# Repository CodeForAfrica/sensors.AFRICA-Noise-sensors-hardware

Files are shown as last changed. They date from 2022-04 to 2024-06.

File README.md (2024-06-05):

# sensors.AFRICA Noise Sensor Kits Hardware

## Tools used

* Autodesk Eagle

* Fusion360

## sensors.AFRICA Stack

1. Firmware - https://github.com/CodeForAfrica/sensors.AFRICA-Noise-sensors-software
2. API - https://github.com/CodeForAfricaLabs/sensors.AFRICA-AQ-api
3. Map - https://github.com/CodeForAfrica/sensors.AFRICA-AQ-map-v2

## Documentation

Latest PCB Design on](https://a360.co/4bMNexy) Fusion360

*Front layer*
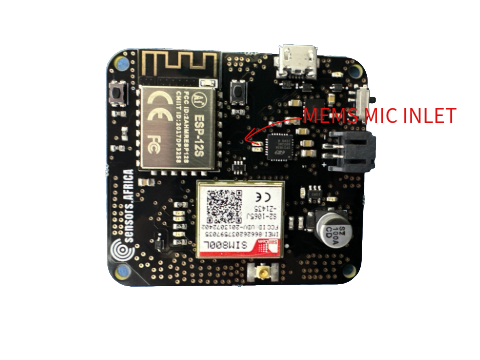
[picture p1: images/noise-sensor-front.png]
Front layer
 

*Back layer*
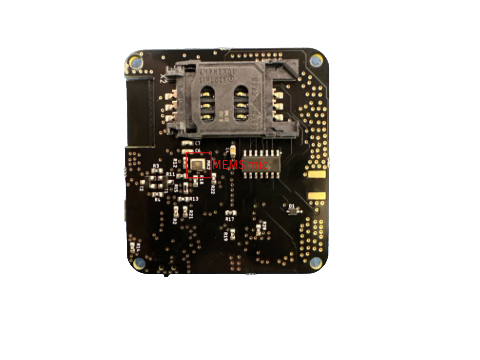
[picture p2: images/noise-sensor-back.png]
Back layer


### Pinout 
- **RX** and **TX** pins on the ESP-12 to communicate to the GSM are **0** and **2** respectively.
- The **GSM RESET** pin is **NOT** physically connected to the ESP module.

## License

GNU General Public License v3.0

sensors.AFRICA is a citizen-science focused project by Code for Africa that seeks to address data gaps by providing low cost sensors, which people can use to measure and monitor the quality of the air, water, and environment in their communities. This web app seeks to be the public portal through which most users would discover and explore the data and intiative.

Copyright (C) 2022 Code for Africa

This program is free software: you can redistribute it and/or modify
it under the terms of the GNU General Public License as published by
the Free Software Foundation, either version 3 of the License, or
(at your option) any later version.

This program is distributed in the hope that it will be useful,
but WITHOUT ANY WARRANTY; without even the implied warranty of
MERCHANTABILITY or FITNESS FOR A PARTICULAR PURPOSE. See the
GNU General Public License for more details.

You should have received a copy of the GNU General Public License
along with this program. If not, see <https://www.gnu.org/licenses/>

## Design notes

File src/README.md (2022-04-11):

# sensors.AFRICA / Noise sensors hardware

This folder contains the Eagle design files for the sensors.AFRICA Noise Sensor boards.

### Folders

* **Noise sensor** The Printed Circuit Board of the Noise Sensor kit

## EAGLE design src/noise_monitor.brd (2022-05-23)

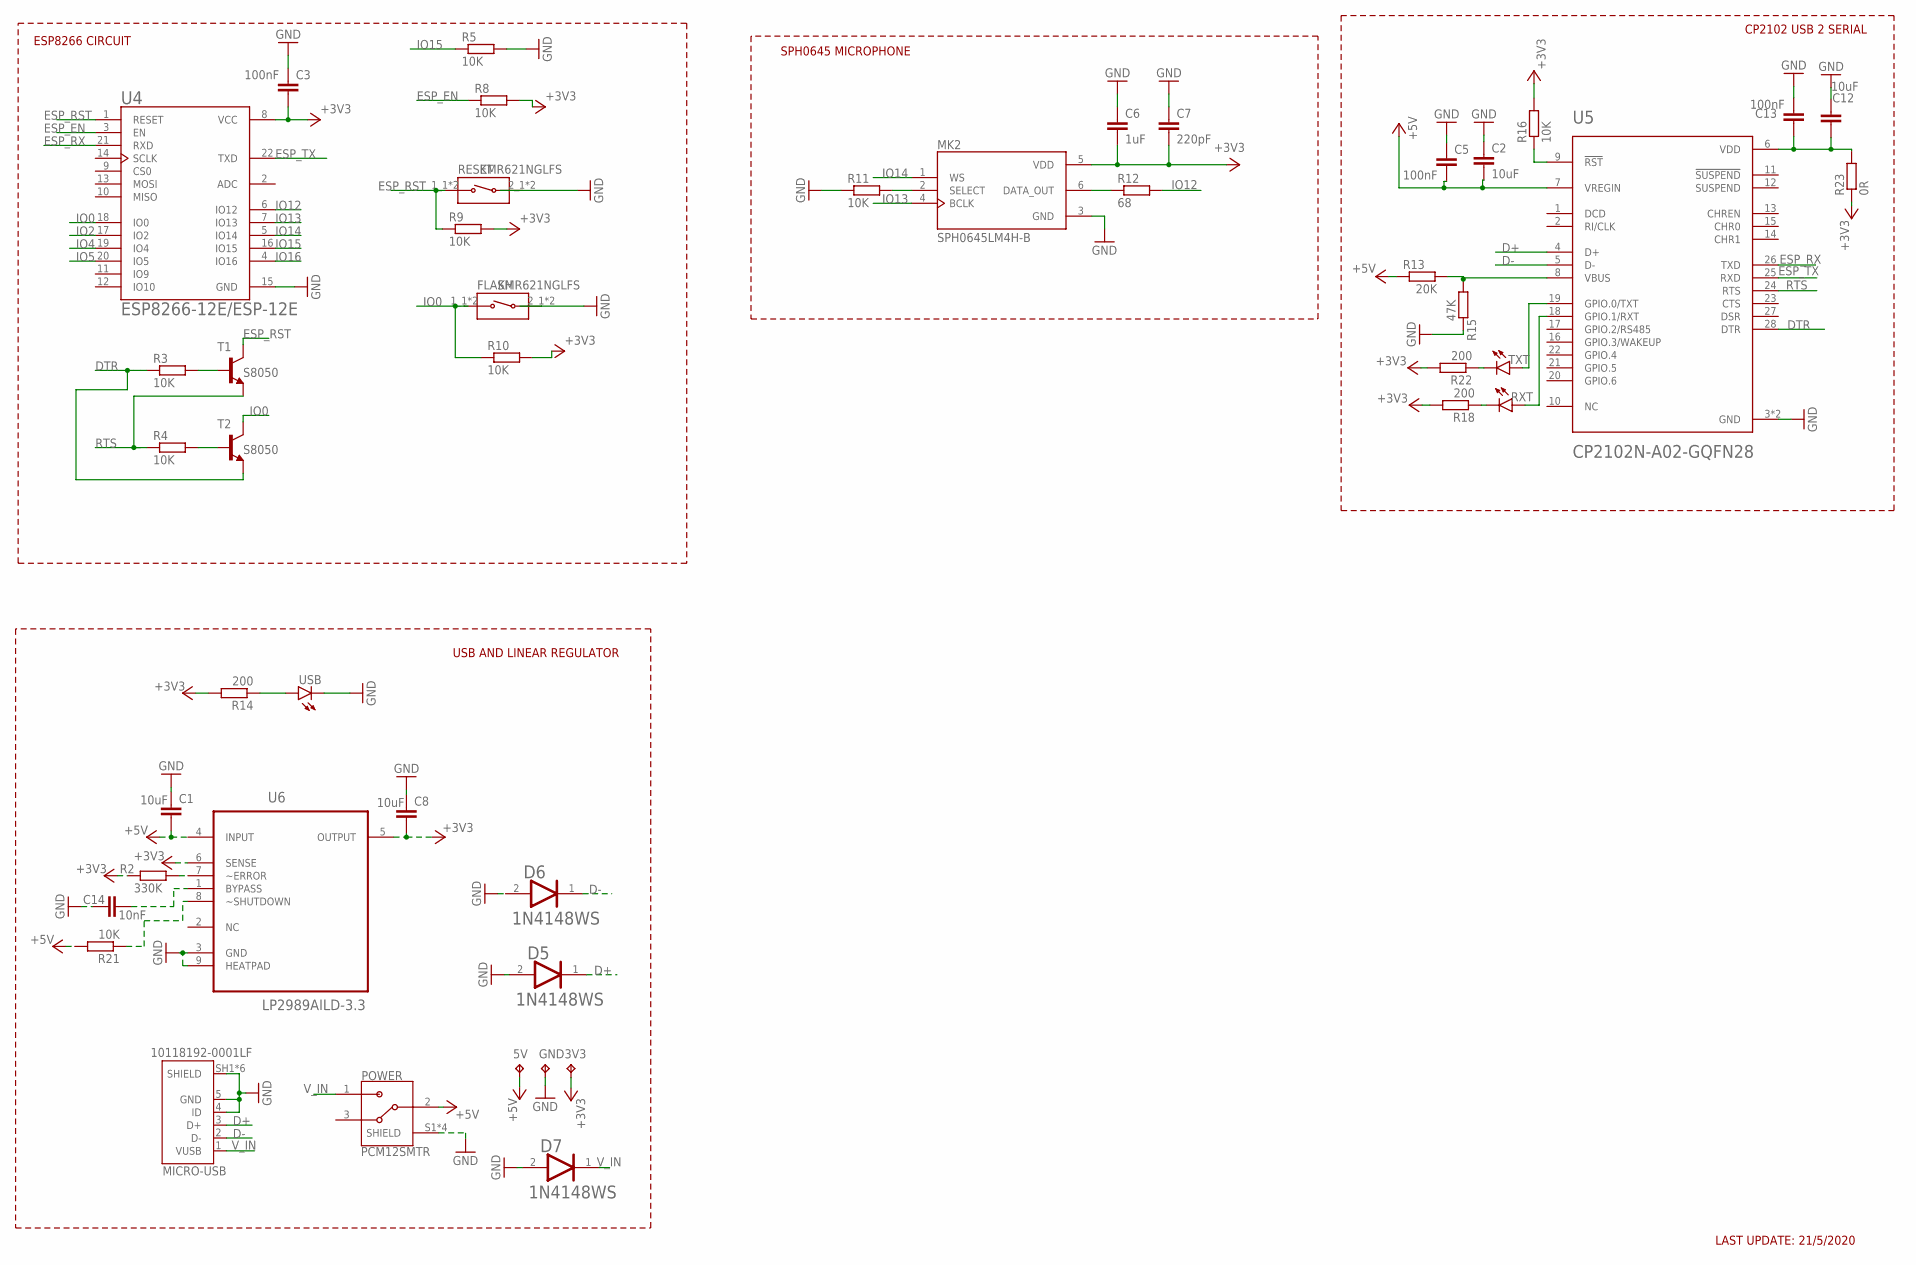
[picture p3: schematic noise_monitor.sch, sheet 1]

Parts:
3V3, 5V: TPTP06R; TP06R
C1, C2, C8, C12: 10uF; C0603
C3, C5, C13: 100nF; C0805
C6: 1uF; C0603
C7: 220pF; C0603
C14: 10nF; C0603
D5, D6, D7: ON_SEMI_1N4148WSON_SEMI_1N4148WS_0_0; ON_SEMI_1N4148WS_0
FLASH: KMR621NGLFS; SW_KMR621NGLFS
GND: TPTP06R; TP06R
MICRO-USB: 10118192-0001LF; AMPHENOL_10118192-0001LF
MK2: SPH0645LM4H-B; MIC_SPH0645LM4H-B
POWER: PCM12SMTR; SW_PCM12SMTR
R2: 330K; R0603
R3, R4, R5, R8, R9, R10, R11, R16, R21: 10K; R0603
R12: 68; R0603
R13: 20K; R0603
R14, R18, R22: 200; R0603
R15: 47K; R0603
R23: 0R; R0201
RESET: KMR621NGLFS; SW_KMR621NGLFS
RXT: LEDCHIP-LED0603; CHIP-LED0603
T1, T2: S8050; SC59-BEC
TXT: LEDCHIP-LED0603; CHIP-LED0603
U4: ESP8266-12E/ESP-12E; XCVR_ESP8266-12E/ESP-12E
U5: CP2102N-A02-GQFN28; QFN50P500X500X80-29N
U6: LP2989AILD-3.3; DFN400X400X80-9N
USB: LEDCHIP-LED0603; CHIP-LED0603

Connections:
+3V3: 3V3.TP, C3.2, C6.2, C7.2, C8.2, MK2.5 (VDD), R2.1, R8.2, R9.2, R10.2, R14.2, R16.2, R18.2, R22.2, R23.1, U4.8 (VCC), U6.5 (OUTPUT), U6.6 (SENSE); also elsewhere on the board
+5V: 5V.TP, C1.2, C2.2, C5.2, POWER.2, R13.1, R21.2, U5.7 (VREGIN), U6.4 (INPUT); also elsewhere on the board
D+: D5.1 (CATHODE), MICRO-USB.3 (D+), U5.4 (D+)
D-: D6.1 (CATHODE), MICRO-USB.2 (D-), U5.5 (D-)
DTR: R3.1, T2.E, U5.28 (DTR)
ESP_EN: R8.1, U4.3 (EN)
ESP_RST: R9.1, RESET.1_1 (1), RESET.1_2 (1), T1.C, U4.1 (RESET)
ESP_RX: U4.21 (RXD), U5.26 (TXD)
ESP_TX: U4.22 (TXD), U5.25 (RXD)
GND: C1.1, C2.1, C3.1, C5.1, C6.1, C7.1, C8.1, C12.1, C13.1, C14.1, D5.2 (ANODE), D6.2 (ANODE), D7.2 (ANODE), FLASH.2_1 (2), FLASH.2_2 (2), GND.TP, MICRO-USB.4 (ID), MICRO-USB.5 (GND), MICRO-USB.SH1 (SHIELD), MICRO-USB.SH2 (SHIELD), MICRO-USB.SH3 (SHIELD), MICRO-USB.SH4 (SHIELD), MICRO-USB.SH5 (SHIELD), MICRO-USB.SH6 (SHIELD), MK2.3 (GND), POWER.S1 (SHIELD), POWER.S2 (SHIELD), POWER.S3 (SHIELD), POWER.S4 (SHIELD), R5.2, R11.1, R15.2, RESET.2_1 (2), RESET.2_2 (2), U4.15 (GND), U5.3 (GND), U5.29 (GND), U6.3 (GND), U6.9 (HEATPAD), USB.C; also elsewhere on the board
IO0: FLASH.1_1 (1), FLASH.1_2 (1), R10.1, T2.C, U4.18 (IO0); also elsewhere on the board
IO2: U4.17 (IO2); also elsewhere on the board
IO4: U4.19 (IO4)
IO5: U4.20 (IO5)
IO12: R12.2, U4.6 (IO12)
IO13: MK2.4 (BCLK), U4.7 (IO13)
IO14: MK2.1 (WS), U4.5 (IO14)
IO15: R5.1, U4.16 (IO15)
IO16: U4.4 (IO16)
unnamed: C12.2, C13.2, R23.2, U5.6 (VDD)
unnamed: R2.2, U6.7 (~ERROR)
unnamed: MK2.2 (SELECT), R11.2
unnamed: R13.2, R15.1, U5.8 (VBUS)
unnamed: R16.1, U5.9 (!RST)
unnamed: R22.1, TXT.C
unnamed: R18.1, RXT.C
unnamed: R3.2, T1.B
unnamed: R4.2, T2.B
unnamed: TXT.A, U5.19 (GPIO.0/TXT)
unnamed: RXT.A, U5.18 (GPIO.1/RXT)
unnamed: C14.2, U6.1 (BYPASS)
unnamed: R21.1, U6.8 (~SHUTDOWN)
unnamed: MK2.6 (DATA_OUT), R12.1
unnamed: R14.1, USB.A
RTS: R4.1, T1.E, U5.24 (RTS)
V_IN: D7.1 (CATHODE), MICRO-USB.1 (VUSB), POWER.1

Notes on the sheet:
LAST UPDATE: 21/5/2020
CP2102 USB 2 SERIAL
SPH0645 MICROPHONE
ESP8266 CIRCUIT
USB AND LINEAR REGULATOR

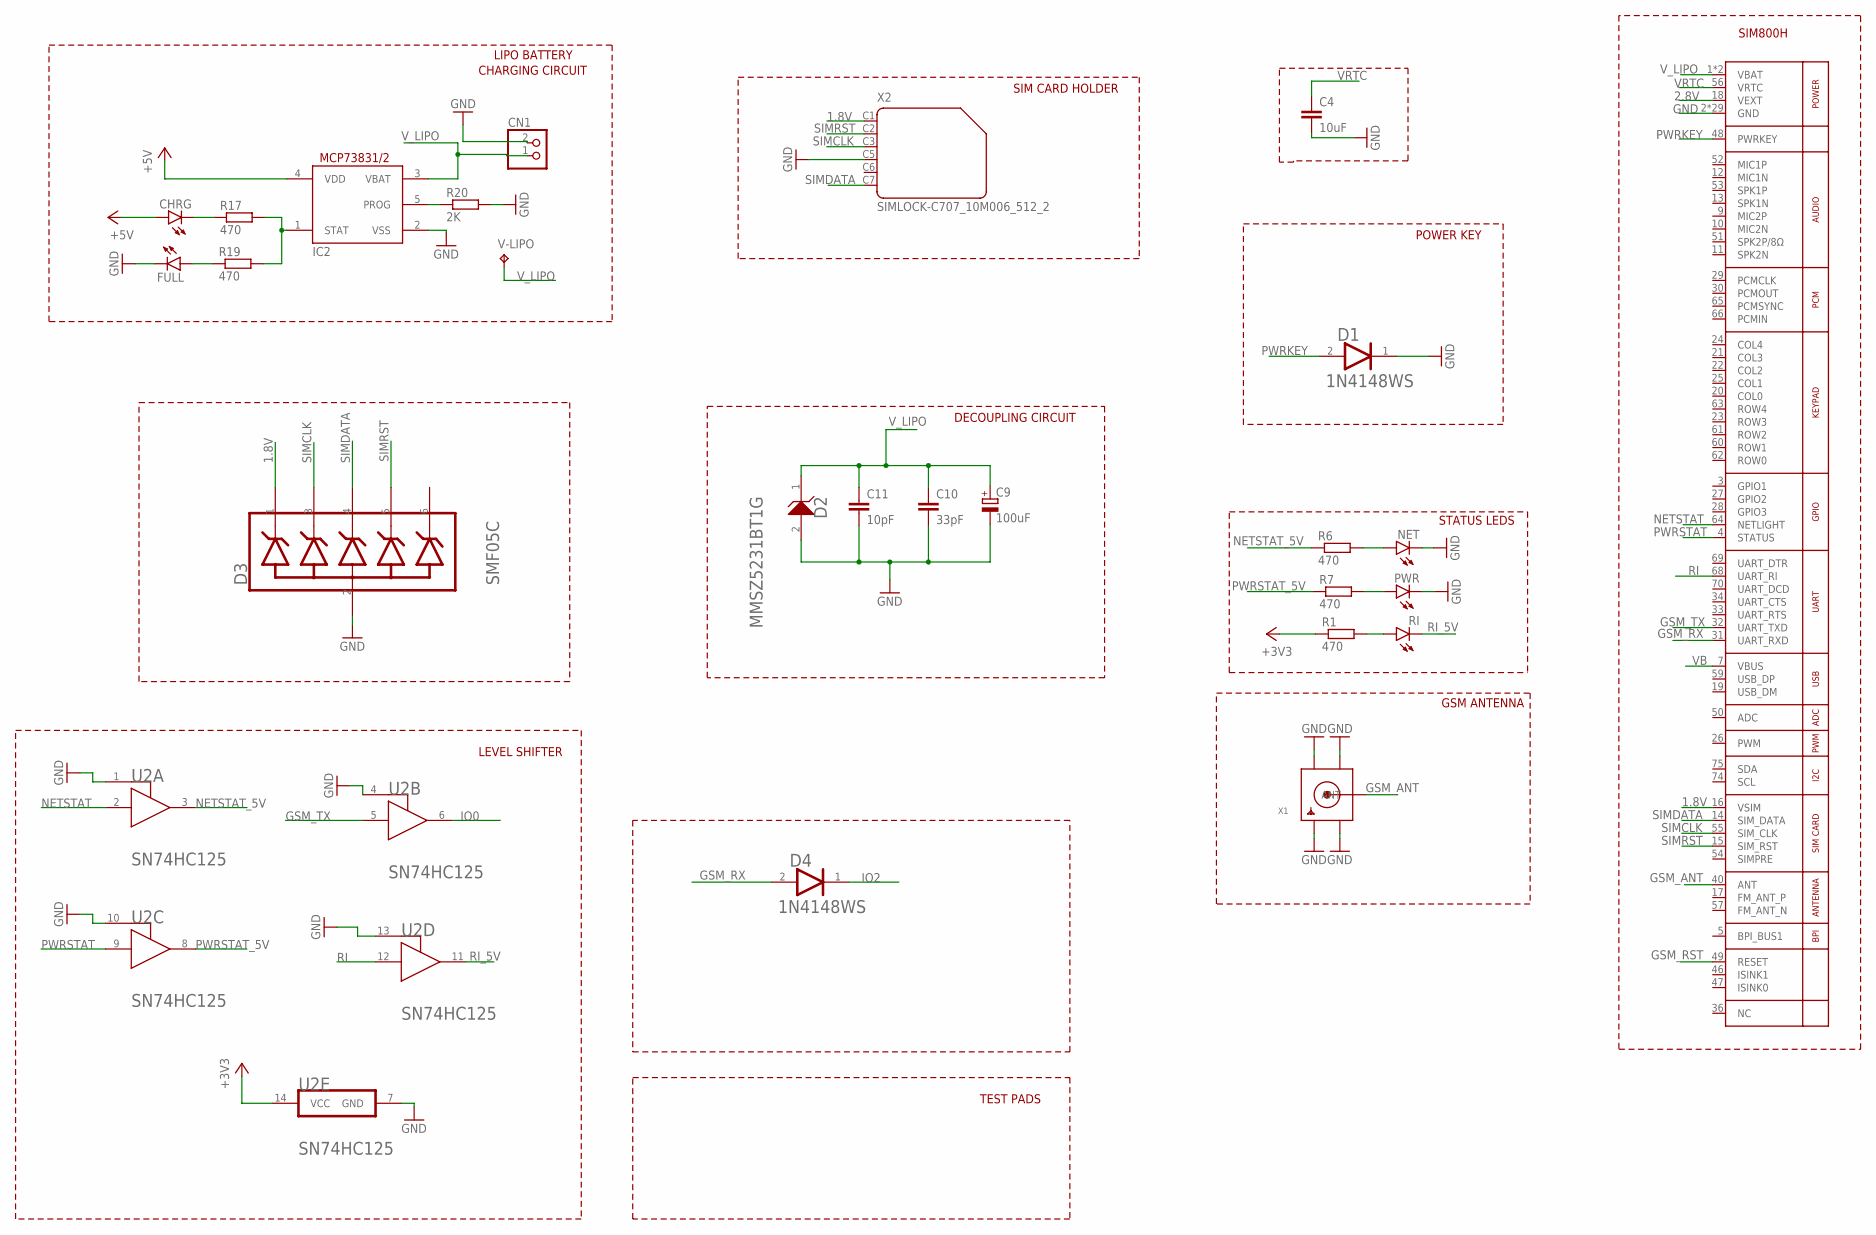
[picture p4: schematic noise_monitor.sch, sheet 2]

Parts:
C4: 10uF; C0603
C9: 100uF; PANASONIC_D
C10: 33pF; C0603
C11: 10pF; C0603
CHRG: LEDCHIP-LED0603; CHIP-LED0603
CN1: JST_2PIN-SMT-RA; JST-PH-2-SMT-RA
D1, D4: ON_SEMI_1N4148WSON_SEMI_1N4148WS_0_0; ON_SEMI_1N4148WS_0
D2: ON_SEMICONDUCTOR_MMSZ5231BT1GON_SEMICONDUCTOR_MMS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; ON_SEMICONDUCTOR_MMSZ5231BT1G_0
D3: SEMTECH_SMF05CSEMTECH_SMF05C_0_0; SEMTECH_SMF05C_0
FULL: LEDCHIP-LED0603; CHIP-LED0603
IC2: MCP73831/OT; SOT23-5L
NET: LEDCHIP-LED0603; CHIP-LED0603
PWR: LEDCHIP-LED0603; CHIP-LED0603
R1, R6, R7, R17, R19: 470; R0603
R20: 2K; R0603
RI: LEDCHIP-LED0603; CHIP-LED0603
U1: GSM_SIM800L; SIM800L
U2: TEXAS_INSTRUMENTS_SN74HC125TEXAS_INSTRUMENTS_SN74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; TEXAS_INSTRUMENTS_SN74HC125_0
V-LIPO: TPTP06R; TP06R
X1: SMACONNECTOR_EDGE_UFL; SMA_EDGELAUNCH_UFL
X2: SIMLOCK-C707_10M006_512_2; C707_10M006_512_2

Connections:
1.8V: D3.1 (1_CATHODE), U1.16 (VSIM), X2.C1 (1)
2.8V: U1.18 (VEXT)
+3V3: R1.1, U2.14 (VCC); also elsewhere on the board
+5V: CHRG.A, IC2.4 (VDD); also elsewhere on the board
GND: C4.2, C9.-, C10.2, C11.2, CN1.2 (1), D1.1 (CATHODE), D2.2 (A), D3.2 (ANODE), FULL.C, IC2.2 (VSS), NET.C, PWR.C, R20.2, U1.2 (GND), U1.6 (GND), U1.8 (GND), U1.35 (GND), U1.37 (GND), U1.38 (GND), U1.39 (GND), U1.41 (GND), U1.43 (GND), U1.44 (GND), U1.45 (GND), U1.58 (GND), U1.67 (GND), U1.71 (GND), U1.72 (GND), U1.73 (GND), U1.76 (GND), U1.77 (GND), U1.78 (GND), U1.79 (GND), U1.80 (GND), U1.81 (GND), U1.82 (GND), U1.83 (GND), U1.84 (GND), U1.85 (GND), U1.86 (GND), U1.87 (GND), U1.88 (GND), U2.1 (1_!OE!), U2.4 (4_!OE!), U2.7 (GND), U2.10 (2_!OE!), U2.13 (3_!OE!), X1.GND@1 (GND1), X1.GND@2 (GND2), X1.GND@3 (GND3), X1.GND@4 (GND4), X2.C5 (4); also elsewhere on the board
GSM_ANT: U1.40 (ANT), X1.P (ANT)
GSM_RST: U1.49 (RESET)
GSM_RX: D4.2 (ANODE), U1.31 (UART_RXD)
GSM_TX: U1.32 (UART_TXD), U2.5 (2A)
IO0: U2.6 (2Y); also elsewhere on the board
IO2: D4.1 (CATHODE); also elsewhere on the board
unnamed: CHRG.C, R17.1
unnamed: IC2.1 (STAT), R17.2, R19.2
unnamed: NET.A, R6.2
unnamed: PWR.A, R7.2
unnamed: FULL.A, R19.1
unnamed: IC2.5 (PROG), R20.1
unnamed: R1.2, RI.A
NETSTAT: U1.64 (NETLIGHT), U2.2 (1A)
NETSTAT_5V: R6.1, U2.3 (1Y)
PWRKEY: D1.2 (ANODE), U1.48 (PWRKEY)
PWRSTAT: U1.4 (STATUS), U2.9 (3A)
PWRSTAT_5V: R7.1, U2.8 (3Y)
RI: U1.68 (UART_RI), U2.12 (4A)
RI_5V: RI.C, U2.11 (4Y)
SIMCLK: D3.3 (2_CATHODE), U1.55 (SIM_CLK), X2.C3 (3)
SIMDATA: D3.4 (3_CATHODE), U1.14 (SIM_DATA), X2.C7 (6)
SIMRST: D3.5 (4_CATHODE), U1.15 (SIM_RST), X2.C2 (2)
VB: U1.7 (VBUS)
VRTC: C4.1, U1.56 (VRTC)
V_LIPO: C9.+, C10.1, C11.1, CN1.1 (2), D2.1 (K), IC2.3 (VBAT), U1.1 (VBAT), U1.42 (VBAT), V-LIPO.TP

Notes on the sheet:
SIM800H
POWER KEY
STATUS LEDS
SIM CARD HOLDER
CHARGING CIRCUIT
LIPO BATTERY
GSM ANTENNA
TEST PADS
LEVEL SHIFTER
DECOUPLING CIRCUIT

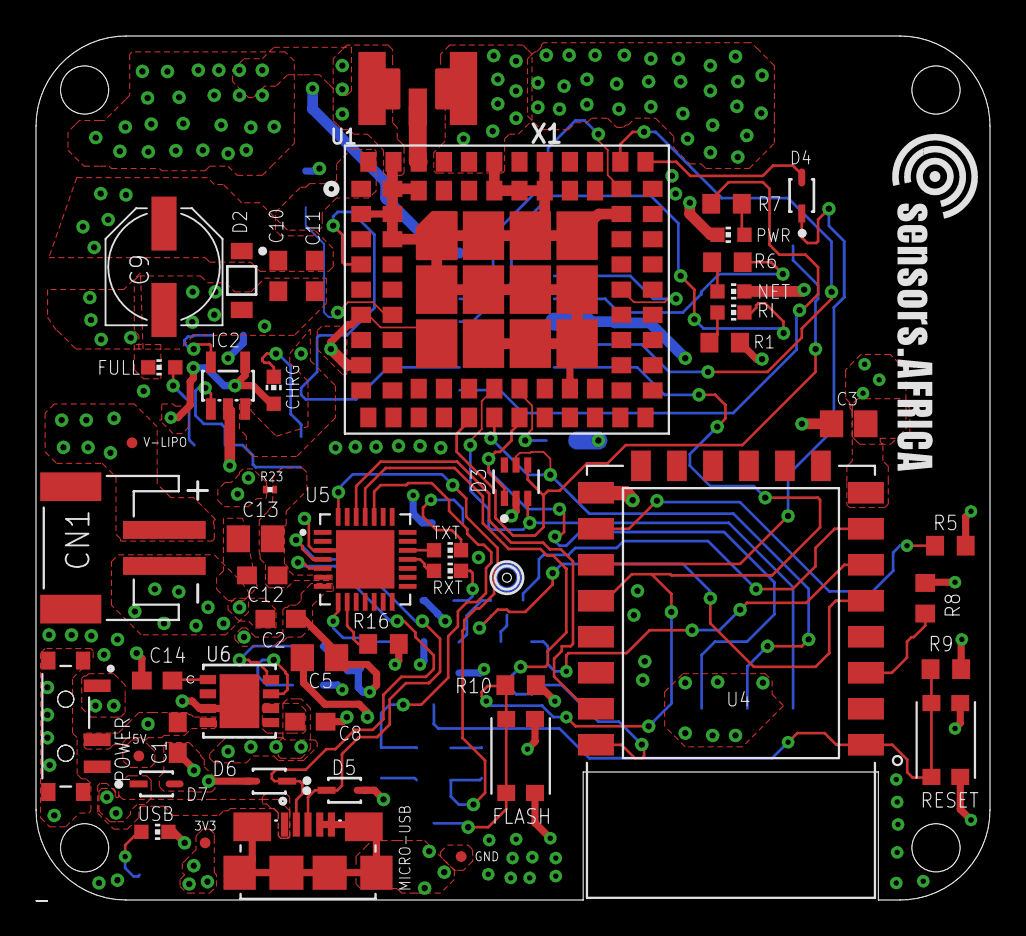
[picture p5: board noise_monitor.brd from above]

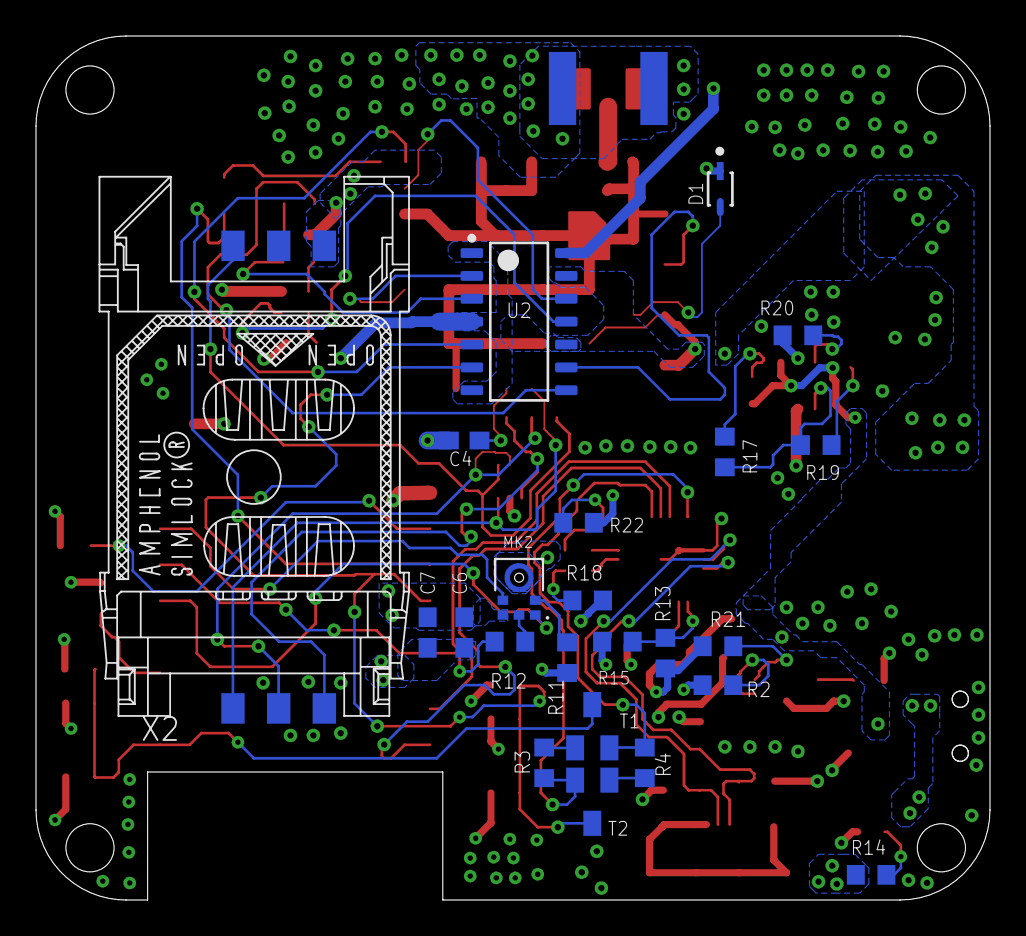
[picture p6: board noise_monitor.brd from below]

Board: 4 copper layers, 53.0 x 48.0 mm, 72 parts (23 on the bottom side), 56 nets.

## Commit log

2022-04-11 added schematic
    [noise_monitor.brd, noise_monitor.sch]
2022-05-11 Fixed DRC
    [noise_monitor.brd, noise_monitor.sch]
2022-05-11 Added CAM files
    [noise_monitor.brd]
2022-05-11 fixed board layers
    [noise_monitor.brd]
2022-05-23 adjusted mounting hole diameter
    [noise_monitor.brd, noise_monitor.sch]
2024-06-04 Addd PCB images
2024-06-05 update pcb images
